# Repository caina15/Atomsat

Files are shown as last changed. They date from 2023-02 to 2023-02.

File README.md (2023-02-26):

# Atomsat
Atomsat is a 9-member project, the aim of the project is to develop and launch a low-cost cubesat 1U (nano satellite in cube format 10 by 10 by 10 cm) for technology demonstration and open doors for scientific experiments in schools around the world . The launch estimate is for the beginning of 2024 and is expected to be in operation for 1 year (caused by orbital decay).
(The project is still under development, codes and PCBs are not ready)

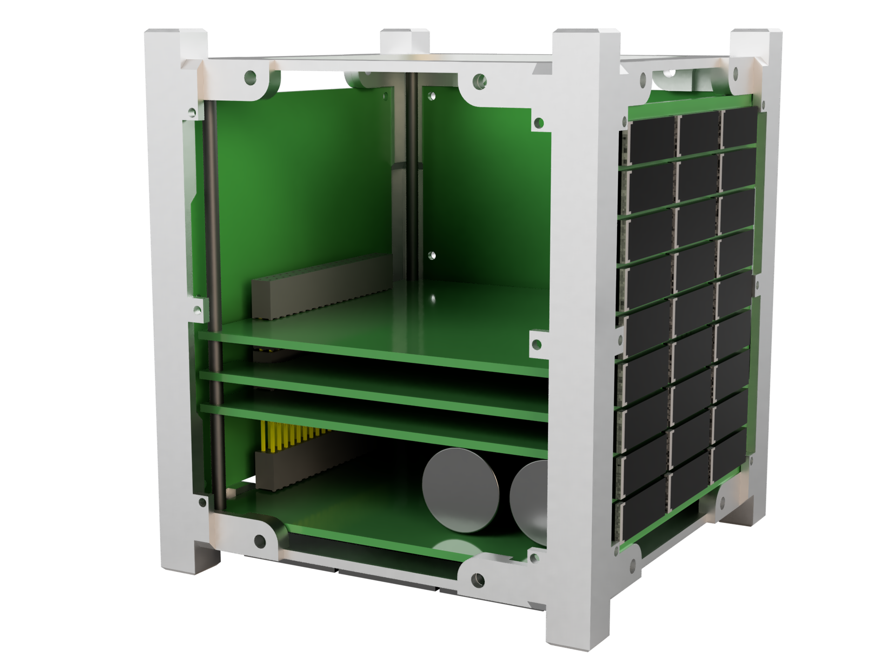
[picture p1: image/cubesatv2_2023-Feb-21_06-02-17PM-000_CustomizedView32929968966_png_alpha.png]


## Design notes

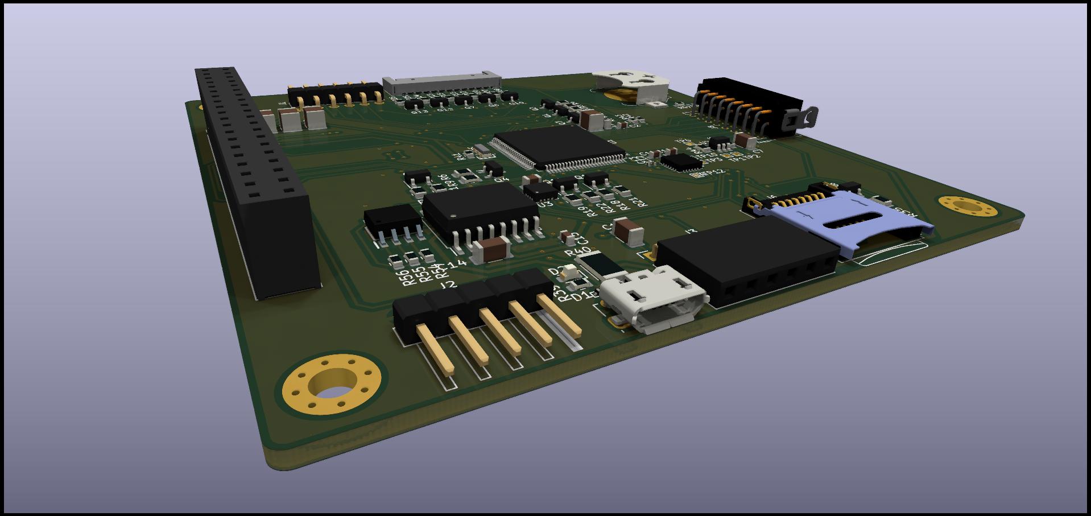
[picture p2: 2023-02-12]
Flight computer hardware/Flight computer.jpg

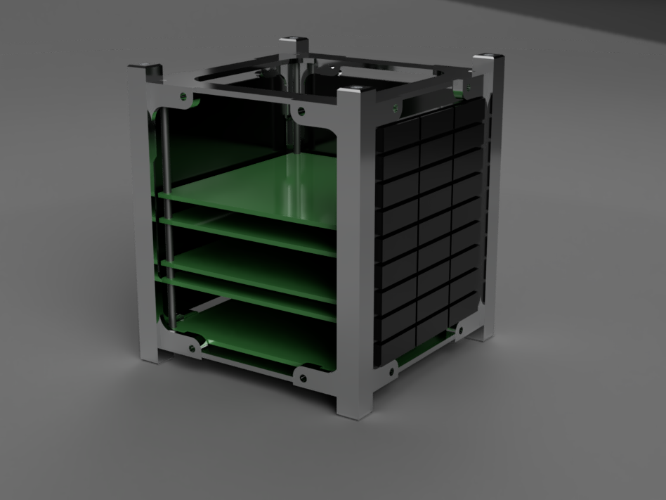
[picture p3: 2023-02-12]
image/cubesatv2_2022-Dec-11_02-06-24PM-000_CustomizedView26116961433_png.png

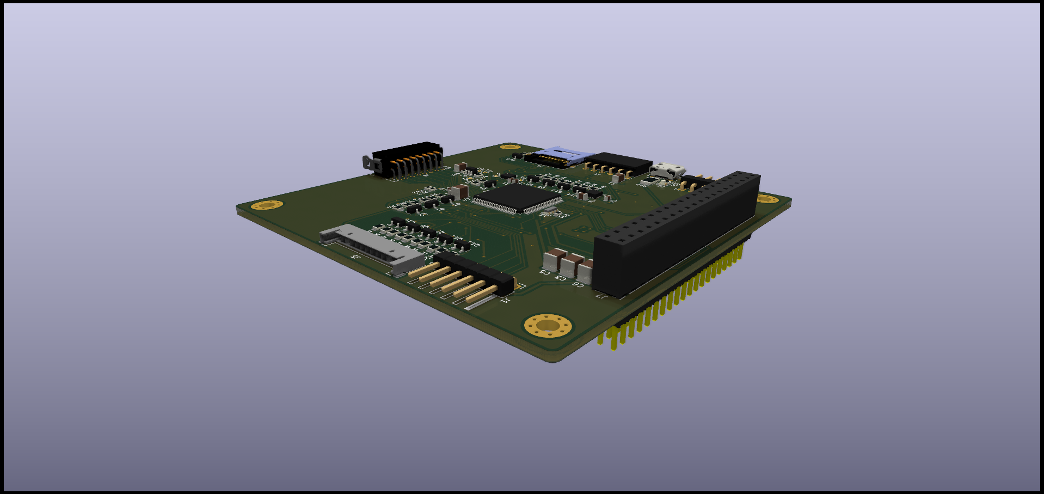
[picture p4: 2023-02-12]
image/Flight computer1.png

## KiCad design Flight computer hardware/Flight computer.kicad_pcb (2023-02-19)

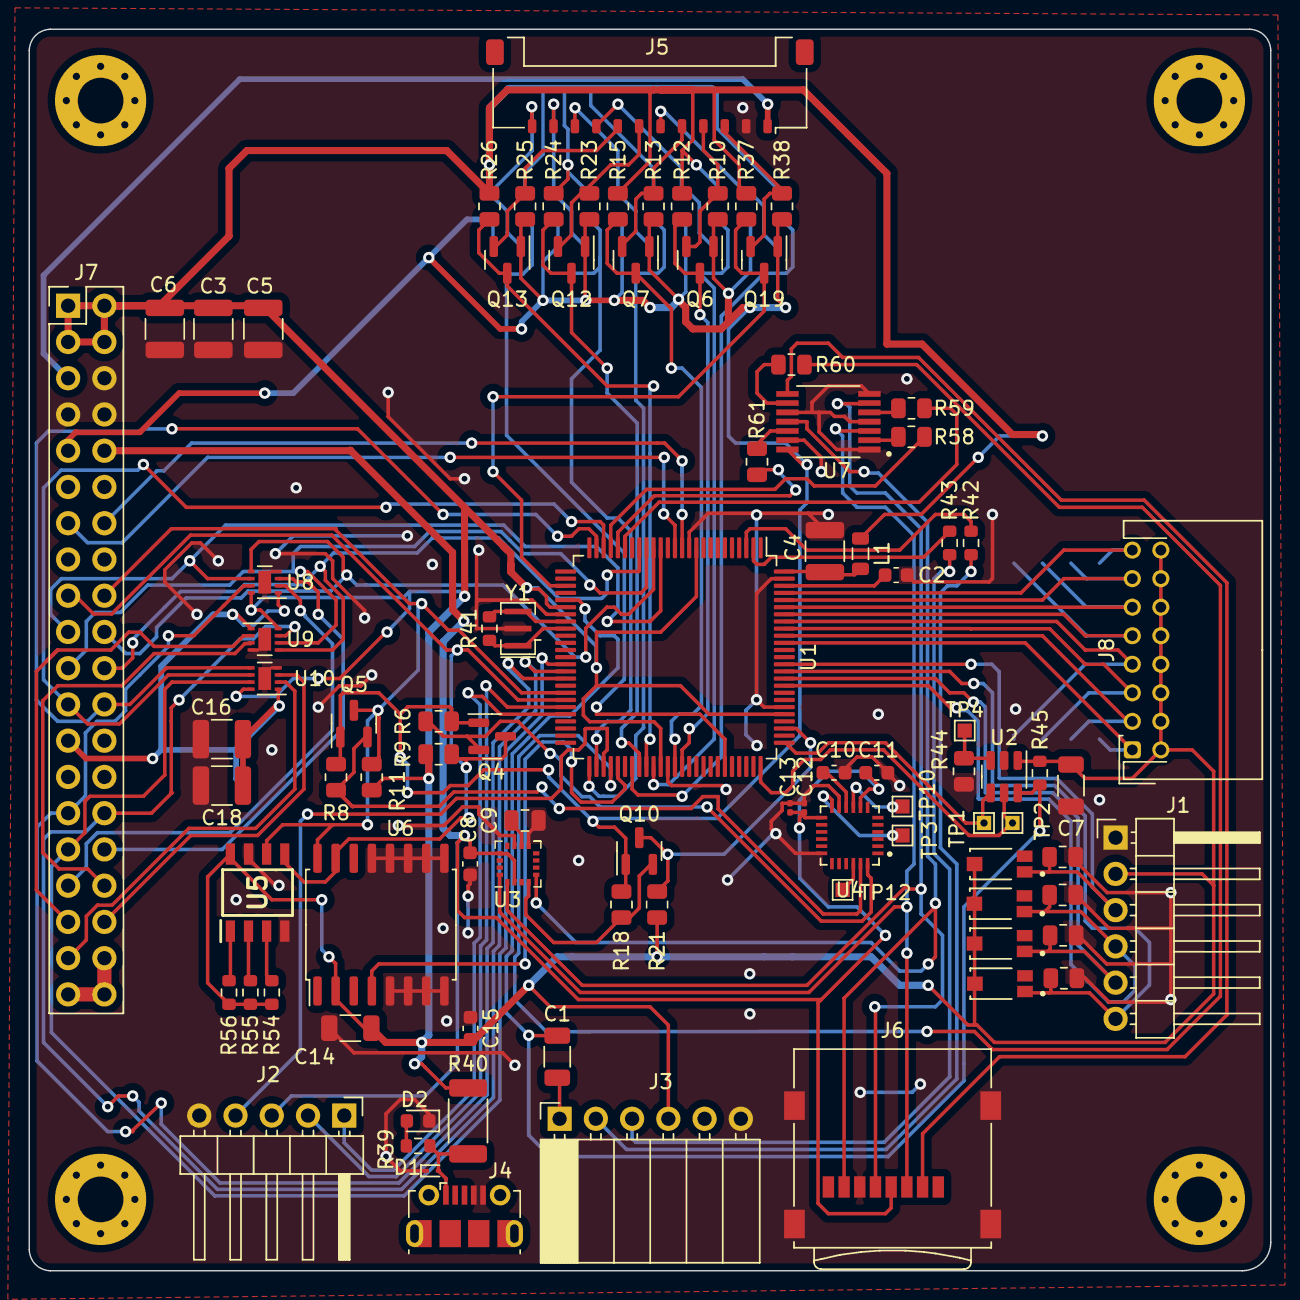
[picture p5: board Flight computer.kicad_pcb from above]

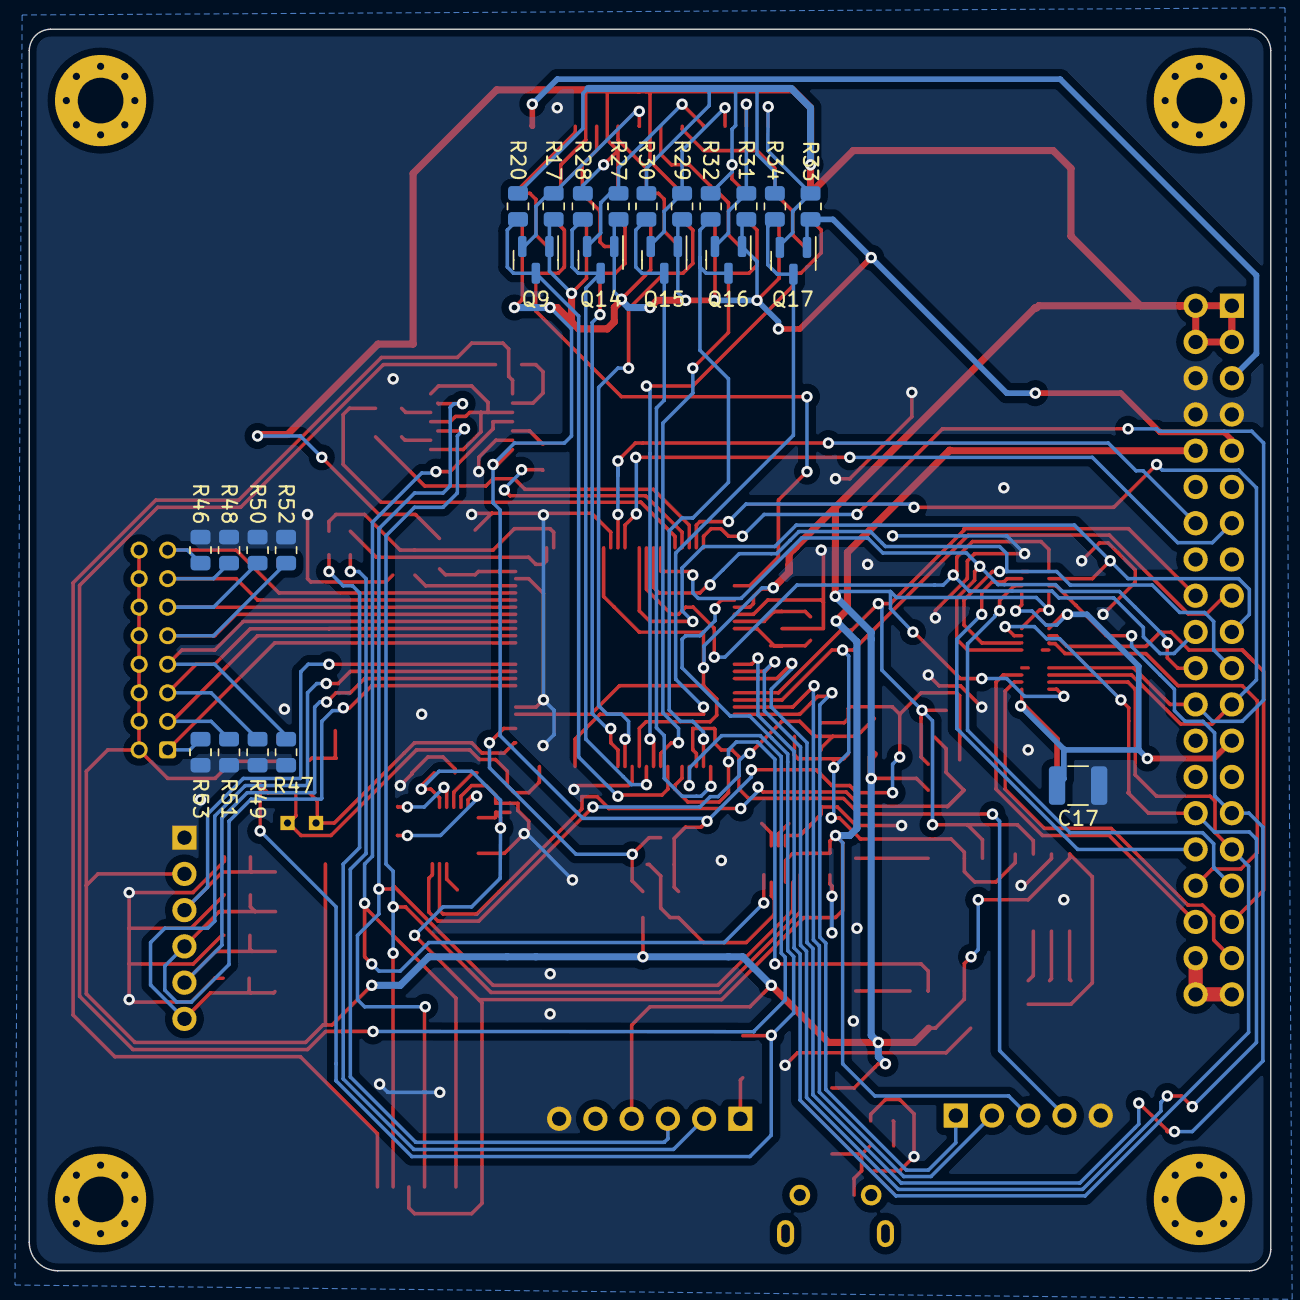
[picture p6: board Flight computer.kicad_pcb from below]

Board: 2 copper layers, 87.0 x 87.0 mm, 119 parts (24 on the bottom side), 101 nets.

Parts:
C1, C7, C14: 0.1uF; C_1206_3216Metric
C2: 100nF; C_0603_1608Metric
C3, C4, C5, C6, C16, C17, C18: 100nF; C_1210_3225Metric
C8, C15: 1uF; C_0603_1608Metric
C9: 10uF; C_0805_2012Metric
C10: 0.47uF; C_0603_1608Metric
C11: 10nF; C_0603_1608Metric
C12, C13: 2.2uF; C_0201_0603Metric
D1: ESD9B5.0ST5G; D_SOD-923
D2: LED_smd; LED_0603_1608Metric
H1, H2, H3, H4: MountingHole; MountingHole_3.2mm_M3_Pad_Via
J1: Conn_01x06_Male; PinHeader_1x06_P2.54mm_Horizontal
J2: Conn_01x05_Male; PinHeader_1x05_P2.54mm_Horizontal
J3: Conn_01x06_Female; PinSocket_1x06_P2.54mm_Horizontal
J4: USB_B; USB_Micro-B_Molex-105017-0001
J5: Conn_01x12_Male; Molex_Pico-Lock_504050-1291_1x12-1MP_P1.50mm_Horizontal
J6: Micro_SD_Card; microSD_HC_Wuerth_693072010801
J7: Conn_02x20_Odd_Even; PinHeader_2x20_P2.54mm_Vertical
J8: Conn_01x16_Male; JST_PHD_S16B-PHDSS_2x08_P2.00mm_Horizontal
L1: 10uH; L_0805_2012Metric
Q1, Q2, Q3, Q8: TEMT6000X01; TRANS_TEMT6000X01
Q4, Q5, Q6, Q7, Q9, Q10, Q12, Q13, Q14, Q15, Q16, Q17, Q19: BSS138; SOT-23
R1, R2, R3, R4, R6, R8, R18, R38, R46, R47, R48, R49, R50, R51, R52, R53: 10K; R_0805_2012Metric
R9, R11, R21, R37: 10k; R_0805_2012Metric
R10, R12, R13, R15, R17, R20, R23, R24, R25, R26, R27, R28, R29, R30, R31, R32, R33, R34: 100K; R_0805_2012Metric
R39: 330; R_0603_1608Metric
R40: 10m; R_2010_5025Metric
R41: 1M; R_0603_1608Metric
R42, R43: 1K; R_0603_1608Metric
R44: 8.87K; R_0805_2012Metric
R45: 10K; R_0603_1608Metric
R54, R55, R56: 4.7K; R_0603_1608Metric
R58, R59, R60, R61: 3.3K; R_0805_2012Metric
TP1, TP2: TP_1x1; TestPoint_THTPad_1.0x1.0mm_Drill0.5mm
TP3, TP4, TP10, TP12: TP_smt_1x1; TestPoint_Pad_1.0x1.0mm
U1: ATmega2560-16A; TQFP-100_14x14mm_P0.5mm
U2: TPL5010; SOT-23-6
U3: MMC5983MA; LGA-16_3x3mm_P0.5mm
U4: ICM-20689; QFN50P400X400X95-24N
U5: AT24C32D-SSHM-B; SOIC127P600X175-8N
U6: DS3231M; SOIC-16W_7.5x10.3mm_P1.27mm
U7: SN74LVC125APWT; SOP65P640X120-14N
U8, U9, U10: DRV8837; WSON-8-1EP_2x2mm_P0.5mm_EP0.9x1.6mm
Y1: 16Mhz; Resonator_SMD_Murata_CSTxExxV-3Pin_3.0x1.1mm

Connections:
3.3V_LOGIC: J7.9, Q4.1 (G), Q5.1 (G), Q6.1 (G), Q7.1 (G), Q9.1 (G), Q10.1 (G), Q12.1 (G), Q13.1 (G), Q14.1 (G), Q15.1 (G), Q16.1 (G), Q17.1 (G), Q19.1 (G), R6.1, R8.1, R10.1, R13.1, R17.1, R18.1, R23.1, R25.1, R27.1, R29.1, R31.1, R33.1, R38.1, U7.14 (VCC)
5V_COIL: C16.2, C17.2, C18.2, J7.25, U8.1 (VM), U9.1 (VM), U10.1 (VM)
+3.3V: C8.1, C11.1, C12.1, C13.1, J2.3, J6.4 (VDD), J7.10, U3.2 (VDD), U3.13 (VDDIO), U4.8 (VDDIO), U4.13 (VDD)
+5V: C3.2, C5.2, C6.2, C7.2, C14.2, C15.2, J1.2, J3.4, J7.1, J7.2, J7.3, J7.4, J8.2, J8.4, J8.6, J8.8, J8.10, J8.12, J8.14, J8.16, L1.2, Q1.3, Q2.3, Q3.3, Q8.3, R9.1, R11.1, R12.1, R15.1, R20.1, R21.1, R24.1, R26.1, R28.1, R30.1, R32.1, R34.1, R37.1, R40.2, R45.2, R54.1, R55.1, R56.1, U1.10 (VCC), U1.31 (VCC), U1.61 (VCC), U1.80 (VCC), U2.1 (VDD), U5.8 (VCC), U6.2 (VCC), U8.8 (VCC), U9.8 (VCC), U10.8 (VCC)
/2560/ADC1: J8.13, R48.2, U1.96 (PF1)
/2560/ADC2: J8.11, R50.2, U1.95 (PF2)
/2560/ADC3: J8.9, R52.2, U1.94 (PF3)
/2560/ADC4: J8.7, R47.2, U1.93 (PF4)
/2560/ADC5: J8.5, R49.2, U1.92 (PF5)
/2560/ADC6: J8.3, R51.2, U1.91 (PF6)
/2560/ADC7: J8.1, R53.2, U1.90 (PF7)
/2560/ADCO: J8.15, R46.2, U1.97 (PF0)
/2560/AREF: C2.2, U1.98 (AREF)
/2560/PA0: Q10.3 (D), R21.2, U1.78 (PA0)
/2560/RX2: J7.14, U1.12 (PH0)
/2560/TX2: J7.13, U1.13 (PH1)
/GYRO/INT: TP3.1, U4.12 (INT)
/GYRO/NCS: TP12.1, U4.22 (NCS)
/GYRO/SCL: Q5.2 (S), R8.2, U4.23 (SCL/SCLK)
/GYRO/SDA: Q4.2 (S), R6.2, U4.24 (SDA/SDI)
/GYRO/SDO: TP10.1, U4.9 (AD0/SDO)
/MAG/CS: Q10.2 (S), R18.2, U3.4 (SPI_CS)
/conn/P_solar: J7.38, J7.39, J7.40
ACS_X_SP: J7.29, U1.41 (PL6), U8.7 (~SLEEP)
ACS_Y_SP: J7.30, U1.40 (PL5), U9.7 (~SLEEP)
ACS_Z_SP: J7.31, U1.39 (PL4), U10.7 (~SLEEP)
CS_SD: R60.2, U1.54 (PC1)
CS_SD_3.3: J6.2 (DAT3/CD), U7.8 (3Y)
DF_CTS: J5.8, Q13.2 (S), R25.2
DF_DCD: J5.6, Q9.2 (S), R17.2
DF_DSR: J5.7, Q12.2 (S), R23.2
DF_DTR: J5.11, Q16.2 (S), R31.2
DF_RI: J5.9, Q14.2 (S), R27.2
DF_RTS: J5.10, Q15.2 (S), R29.2
DF_S_RX: J5.5, Q7.2 (S), R13.2
DF_S_TX: J5.4, Q6.2 (S), R10.2
DONE: TP1.1, U1.76 (PA2), U2.4 (DONE)
EN_X: J7.20, U1.16 (PH4), U8.5 (IN2)
EN_Y: J7.22, U1.18 (PH6), U9.5 (IN2)
EN_Z: J7.24, U1.24 (PB5), U10.5 (IN2)
EXT_PWR: J5.1, J7.5
FC_RX3: Q7.3 (D), R15.2, U1.63 (PJ0)
FC_TX3: Q6.3 (D), R12.2, U1.64 (PJ1)
GND: C2.1, C3.1, C4.1, C5.1, C6.1, C7.1, C8.2, C9.2, C10.2, C11.2, C12.2, C13.2, C14.1, C15.1, C16.1, C17.1, C18.1, D1.1 (A1), D2.1 (K), J1.1, J2.5, J3.6, J4.4 (GND), J4.5 (Shield), J5.2, J6.6 (VSS), J6.9 (SHIELD), J7.6, J7.7, J7.8, R1.2, R2.2, R3.2, R4.2, R44.2, R46.1, R47.1, R48.1, R49.1, R50.1, R51.1, R52.1, R53.1, U1.11 (GND), U1.32 (GND), U1.62 (GND), U1.81 (GND), U1.99 (GND), U2.2 (GND), U3.9 (VSS), U3.11 (VSS), U4.11 (FSYNC), U4.18 (GND), U5.4 (GND), U5.7 (WP), U6.5 (GND), U6.6 (GND), U6.7 (GND), U6.8 (GND), U6.9 (GND), U6.10 (GND), U6.11 (GND), U6.12 (GND), U6.13 (GND), U7.1 (1~OE), U7.4 (2~OE), U7.7 (GND), U7.10 (3~OE), U7.13 (4~OE), U8.4 (GND), U8.9 (GND), U9.4 (GND), U9.9 (GND), U10.4 (GND), U10.9 (GND), Y1.2
MISO_3.3V: J6.7 (DAT0), U3.5 (SPI_SDO), U7.11 (4Y)
MISO_5V: R61.2, U1.21 (PB2)
MOSI_3.3V: J6.3 (CMD), U3.16 (SDA/SPI_SDI), U7.3 (1Y)
MOSI_5V: R58.2, U1.22 (PB3)
NET_AVAILABLE: J5.12, Q17.2 (S), R33.2
unnamed: C1.2, J3.1
unnamed: C4.2, L1.1, U1.100 (AVCC)
unnamed: C9.1, U3.10 (CAP)
unnamed: C10.1, U4.10 (REGOUT)
unnamed: D1.2 (A2), J4.1 (VBUS), R39.2, R40.1
unnamed: D2.2 (A), R39.1
unnamed: J5.3, Q19.2 (S), R38.2
unnamed: R41.1, U1.34 (XTAL1), Y1.1
unnamed: R41.2, U1.33 (XTAL2), Y1.3
unnamed: R42.1, U1.3 (PE1)
unnamed: R43.1, U1.2 (PE0)
unnamed: R44.1, TP4.1, U2.3 (DELAY/M_RST)
unnamed: R54.2, U5.3 (A2)
unnamed: R55.2, U5.2 (A1)
unnamed: R56.2, U5.1 (A0)
unnamed: R58.1, U7.2 (1A)
unnamed: R59.1, U7.5 (2A)
unnamed: R60.1, U7.9 (3A)
unnamed: R61.1, U7.12 (4A)
ON/OFF_iridium: Q19.3 (D), R37.2, U1.28 (PG3)
OUT1X: J7.33, U8.2 (OUT1)
OUT1Y: J7.35, U9.2 (OUT1)
OUT1Z: J7.37, U10.2 (OUT1)
OUT2X: J7.32, U8.3 (OUT2)
OUT2Y: J7.34, U9.3 (OUT2)
OUT2Z: J7.36, U10.3 (OUT2)
PC4: Q9.3 (D), R20.2, U1.57 (PC4)
PC5: Q12.3 (D), R24.2, U1.58 (PC5)
PC6: Q13.3 (D), R26.2, U1.59 (PC6)
PC7: Q14.3 (D), R28.2, U1.60 (PC7)
PG0: Q15.3 (D), R30.2, U1.51 (PG0)
PG1: Q16.3 (D), R32.2, U1.52 (PG1)
PG2: Q17.3 (D), R34.2, U1.70 (PG2)
PH_X: J7.19, U1.15 (PH3), U8.6 (IN1)
PH_Y: J7.21, U1.17 (PH5), U9.6 (IN1)
PH_Z: J7.23, U1.23 (PB4), U10.6 (IN1)
RESET: C1.1, R45.1, U1.30 (~RESET), U2.6 (~RST)
RESET_GPS: J2.4, U1.53 (PC0)
RX0: J3.3, R43.2
RX_GPS: J2.2, U1.45 (PD2)
S1: J1.3, Q1.1, R1.1, U1.87 (PK2)
S2: J1.6, Q8.1, R4.1, U1.86 (PK3)
S3: J1.5, Q3.1, R3.1, U1.85 (PK4)
S4: J1.4, Q2.1, R2.1, U1.84 (PK5)
SCK_3.3V: J6.5 (CLK), U3.1 (SCL/SPI_SCK), U7.6 (2Y)
SCK_5V: R59.2, U1.20 (PB1)
SCL: J7.18, Q5.3 (D), R11.2, U1.43 (PD0), U5.6 (SCL), U6.16 (SCL)
SDA: J7.17, Q4.3 (D), R9.2, U1.44 (PD1), U5.5 (SDA), U6.15 (SDA)
TX0: J3.2, R42.2
TX_GPS: J2.1, U1.46 (PD3)
WAKE: TP2.1, U1.75 (PA3), U2.5 (WAKE)
rst_ds: U1.55 (PC2), U6.4 (~RST)

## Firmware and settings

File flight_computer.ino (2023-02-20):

#include "RTClib.h"
#include "Wire.h"
#include <SPI.h>
#include "ICM20689.h"
#include <SparkFun_MMC5983MA_Arduino_Library.h> //Click here to get the library: http://librarymanager/All#SparkFun_MMC5983MA
#include <SD.h>

void mag();
void gyro();

File dataFile;
SFE_MMC5983MA myMag;

#define csmag  PA0 //mega pin 22
#define rst_ds PC2 //mega pin 35

#define PH_X  PH3 //mega pin 6
#define EN_X  PH4 //mega pin 7
#define SP_X  PL4 //mega pin 45
#define PH_Y  PH5 //mega pin 8
#define EN_Y  PH6 //mega pin 9
#define SP_Y  PL5 //mega pin 44
#define PH_Z  PB4 //mega pin 10
#define EN_Z  PB5 //mega pin 11
#define SP_Z  PL6 //mega pin 43

ICM20689 IMU(Wire,0x68);

RTC_DS3231 rtc;

int statusINM;
uint32_t currentX, currentY, currentZ = 0;  //MAG
double normalizedX, normalizedY, normalizedZ = 0; //MAG
unsigned long millisgeralpre = 0; //SD
const long intervaloSD = 500; //SD
int celsius = 0;  //MAG
int PHX, ENX, SPX = 0; //ACS X
int PHY, ENY, SPY = 0; //ACS Y
int PHZ, ENZ, SPZ = 0; //ACS Z
String receEarth, codRTC;
DateTime ajsttime;

void setup()
{
 PORTC = PORTC | (1<< PC2);
 
  Serial.begin(115200);
  Serial1.begin(9600);
  Serial2.begin(115200);
  
  while(!Serial) {}
  SPI.begin();
  
  Serial.print("Initializing SD card...");
  if (!SD.begin(4)) {
    Serial.println("initialization failed!");
  }else{
    Serial.println("initialization done.");
  }

  // start communication with IMU
  statusINM = IMU.begin();
  if (statusINM < 0) {
    Serial.println("IMU initialization unsuccessful");
    Serial.print("statusINM: ");
    Serial.println(statusINM);
  }
  Serial.println("temp ICM20689,X Mag axis raw value,Y Mag axis raw value,Z Mag axis raw value,X axis field (Gauss),Y axis field (Gauss),Z axis field (Gauss),ax,ay,az,gx,gy,gz,temp_C");

    if (myMag.begin(csmag) == false)
    {
      Serial.println("MMC5983MA did not respond");
    }else{
    Serial.println("MMC5983MA connected");
    }
    myMag.softReset();
}

void loop()
{
unsigned long millisgeral = millis();  
  mag();
  gyro();
  if (millisgeral - millisgeralpre >= intervaloSD) {
    millisgeralpre = millisgeral;
    dataFile = SD.open("data.txt", FILE_WRITE);
    if (dataFile){
      dataFile.print(celsius);
      dataFile.print("\t");
      dataFile.print(currentX);
      dataFile.print("\t");
      dataFile.print(currentY);
      dataFile.print("\t");
      dataFile.print(currentZ);
      dataFile.print("\t");
      dataFile.print(normalizedX * 8, 5); // Print with 5 decimal places
      dataFile.print("\t");    
      dataFile.print(normalizedY * 8, 5);
      dataFile.print("\t");
      dataFile.print(normalizedZ * 8, 5);
      dataFile.print("\t");
      dataFile.print(IMU.getAccelX_mss(),6);
      dataFile.print("\t");
      dataFile.print(IMU.getAccelY_mss(),6);
      dataFile.print("\t");
      dataFile.print(IMU.getAccelZ_mss(),6);
      dataFile.print("\t");
      dataFile.print(IMU.getGyroX_rads(),6);
      dataFile.print("\t");
      dataFile.print(IMU.getGyroY_rads(),6);
      dataFile.print("\t");
      dataFile.print(IMU.getGyroZ_rads(),6);
      dataFile.print("\t");
      dataFile.print(IMU.getTemperature_C(),6);   
      dataFile.println();

      dataFile.close();
      Serial.print(F("SD write"));
    }else {
    Serial.print(F("error write"));
    }
  }  
}
void mag(){
  
  int celsius = myMag.getTemperature();
  float fahrenheit = (celsius * 9.0f / 5.0f) + 32.0f;
  Serial.print(celsius);
  Serial.print("\t"); 
  
  // This reads the X, Y and Z channels mag consecutively
  currentX = myMag.getMeasurementX();
  currentY = myMag.getMeasurementY();
  currentZ = myMag.getMeasurementZ();

  // Or, we could read all three simultaneously
  //myMag.getMeasurementXYZ(&currentX, &currentY, &currentZ);

  Serial.print(currentX);
  Serial.print("\t");
  Serial.print(currentY);
  Serial.print("\t");
  Serial.print(currentZ);
  Serial.print("\t");

  // The magnetic field values are 18-bit unsigned. The zero (mid) point is 2^17 (131072).
  // Normalize each field to +/- 1.0
  normalizedX = (double)currentX - 131072.0;
  normalizedX /= 131072.0;
  normalizedY = (double)currentY - 131072.0;
  normalizedY /= 131072.0;
  normalizedZ = (double)currentZ - 131072.0;
  normalizedZ /= 131072.0;
  
  // The magnetometer full scale is +/- 8 Gauss
  // Multiply the normalized values by 8 to convert to Gauss
  Serial.print(normalizedX * 8, 5); // Print with 5 decimal places
  Serial.print("\t");    
  Serial.print(normalizedY * 8, 5);
  Serial.print("\t");
  Serial.print(normalizedZ * 8, 5);
  Serial.print("\t");
    
}
void gyro(){
  // read the sensor
  IMU.readSensor();
  // display the data
  Serial.print(IMU.getAccelX_mss(),6);
  Serial.print("\t");
  Serial.print(IMU.getAccelY_mss(),6);
  Serial.print("\t");
  Serial.print(IMU.getAccelZ_mss(),6);
  Serial.print("\t");
  Serial.print(IMU.getGyroX_rads(),6);
  Serial.print("\t");
  Serial.print(IMU.getGyroY_rads(),6);
  Serial.print("\t");
  Serial.print(IMU.getGyroZ_rads(),6);
  Serial.print("\t");
  Serial.print(IMU.getTemperature_C(),6);   
  Serial.println(); 
  }
void ACS(){
  //CONTROL ACS
  digitalWrite(SP_X, SPX);  //Set direction X
  digitalWrite(PH_X, PHX);  //enable X
  analogWrite(EN_X, ENX);   //control X
    
  digitalWrite(SP_X, SPX);  //Set direction Y
  digitalWrite(PH_X, PHX);  //enable Y
  analogWrite(EN_X, ENX);   //control Y
  
  digitalWrite(SP_X, SPX);  //Set direction Z
  digitalWrite(PH_X, PHX);  //enable Z
  analogWrite(EN_X, ENX);   //control Z
}
void RTCds(){
  
  DateTime now = rtc.now(); // get the current time
//para receber dados usar assim\/\/
/*
  Serial.print(now.year(), DEC);
  Serial.print('/');
  Serial.print(now.month(), DEC);
  Serial.print('/');
  Serial.print(now.day(), DEC);
  Serial.print(' ');
  Serial.print(now.hour(), DEC);
  Serial.print(':');
  Serial.print(now.minute(), DEC);
  Serial.print(':');
  Serial.print(now.second(), DEC);
  Serial.println();  
*/  
}
void RebDataRTC(){
  if(receEarth == codRTC){
    rtc.adjust(ajsttime); //(ANO), (MÊS), (DIA), (HORA), (MINUTOS), (SEGUNDOS)
  }
}

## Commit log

2023-02-12 Add files via upload
    KiCad Board
    [2560.kicad_sch, Flight computer.kicad_pcb, Flight computer.kicad_sch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]
2023-02-12 flight computer KiCad
    [2560.kicad_sch, Flight computer.kicad_pcb, Flight computer.kicad_sch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]
2023-02-19 atualização ACS
    [2560.kicad_sch, ACS.kicad_sch, Flight computer.kicad_pcb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]
2023-02-20 Declared void mag and void gyro
